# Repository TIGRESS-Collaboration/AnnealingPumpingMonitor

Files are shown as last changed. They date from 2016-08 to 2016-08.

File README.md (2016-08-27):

# AnnealingPumpingMonitor
Contains code and PCD designs and documentation regarding the remote monitor station for HPGe detector annealing and pumping.

In PAMonitor_Interface_Board you'll find the Eagle CAD design files for the PCB. 

In RaspberryPi_Code you'll find the home directory of the webserver which contains all the code necessary to run the monitor system.

Some notes:
1) The UUGear library included here must be used, there were some lines of code which needed to be commented out to tame excessive messages to the system logs.
2) readData.c is deprecated. Use readData.cpp
3) Same as above for build.sh and buildcpp.sh, respectively.
4) runMonitorStn.sh was to be a script that could be launched to do all work and checks necessary to ensure the monitor station would run, however, there are still some bugs to be ironed out.

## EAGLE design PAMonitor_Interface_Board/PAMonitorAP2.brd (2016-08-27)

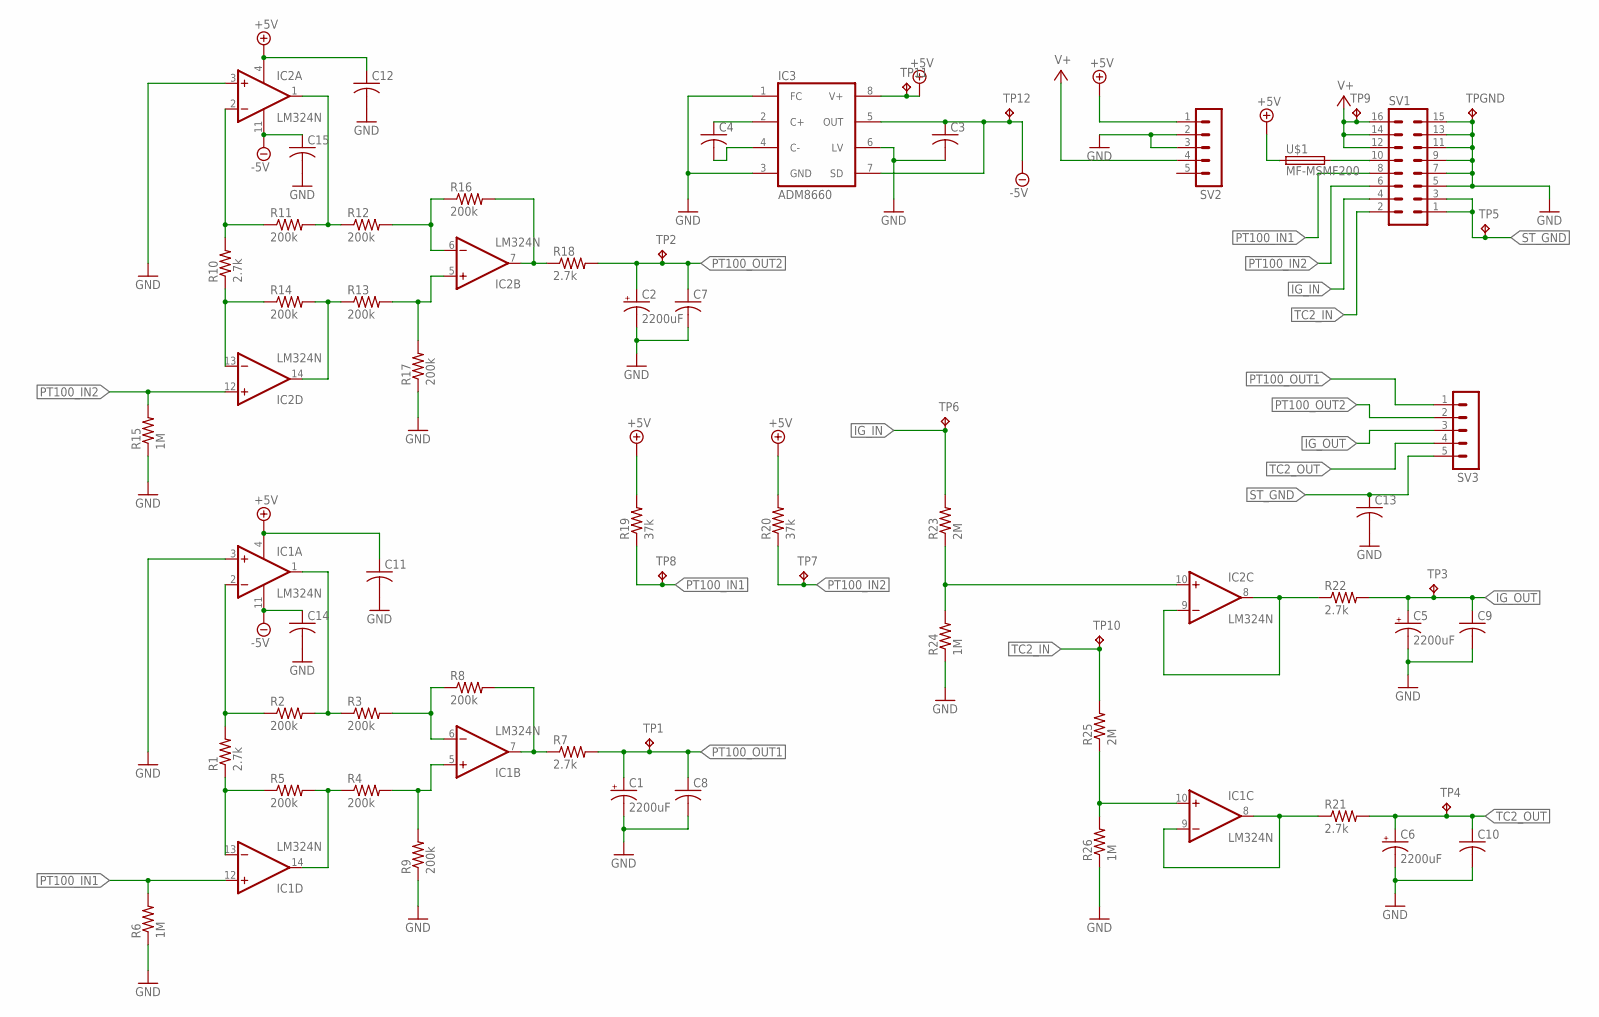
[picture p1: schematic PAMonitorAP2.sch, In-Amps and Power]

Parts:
C1, C2, C5, C6: 2200uF; E5-10,5
C3, C4, C7, C8, C9, C10, C11, C12, C13, C14, C15: C-US025-025X050; C025-025X050
IC1, IC2: LM324N; DIL14
IC3: ADM8660; ADM8660-DIL08
R1, R7, R10, R18, R21, R22: 2.7k; 0309/12
R2, R3, R4, R5, R8, R9, R11, R12, R13, R14, R16, R17: 200k; 0309/12
R6, R15, R24, R26: 1M; 0309/12
R19, R20: 37k; 0309/12
R23, R25: 2M; 0309/12
SV1: MA08-2
SV2, SV3: MA05-1
TP1, TP2, TP3, TP4, TP5, TP6, TP7, TP8, TP9, TP10, TP11, TP12: TPB2,54; B2,54
TPGND: TPB2,54; B2,54
U$1: MF-MSMF200

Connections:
+5V: C11.1, C12.1, IC1.4 (V+), IC2.4 (V+), IC3.8 (V+), R19.2, R20.2, SV2.1, TP11.TP, U$1.1
-5V: C3.1, C14.1, C15.1, IC1.11 (V-), IC2.11 (V-), IC3.5 (OUT), IC3.7 (SD), TP12.TP
GND: C1.-, C2.-, C3.2, C5.-, C6.-, C7.2, C8.2, C9.2, C10.2, C11.2, C12.2, C13.2, C14.2, C15.2, IC1.3 (+IN), IC2.3 (+IN), IC3.1 (FC), IC3.3 (GND), IC3.6 (LV), R6.1, R9.1, R15.1, R17.1, R24.1, R26.1, SV1.5, SV1.7, SV1.9, SV1.11, SV1.13, SV1.15, SV2.2, SV2.3, TPGND.TP
IG_IN: R23.2, SV1.4, TP6.TP
IG_OUT: C5.+, C9.1, R22.2, SV3.3, TP3.TP
unnamed: IC1.13 (-IN), R1.1, R5.1
unnamed: IC1.2 (-IN), R1.2, R2.1
unnamed: IC1.1 (OUT), R2.2, R3.1
unnamed: IC1.6 (-IN), R3.2, R8.1
unnamed: IC1.5 (+IN), R4.2, R9.2
unnamed: IC1.14 (OUT), R4.1, R5.2
unnamed: IC1.7 (OUT), R7.1, R8.2
unnamed: IC2.13 (-IN), R10.1, R14.1
unnamed: IC2.2 (-IN), R10.2, R11.1
unnamed: IC2.1 (OUT), R11.2, R12.1
unnamed: IC2.6 (-IN), R12.2, R16.1
unnamed: IC2.5 (+IN), R13.2, R17.2
unnamed: IC2.14 (OUT), R13.1, R14.2
unnamed: IC2.7 (OUT), R16.2, R18.1
unnamed: C4.1, IC3.2 (C+)
unnamed: C4.2, IC3.4 (C-)
unnamed: SV1.10, U$1.2
unnamed: IC2.8 (OUT), IC2.9 (-IN), R22.1
unnamed: IC1.8 (OUT), IC1.9 (-IN), R21.1
unnamed: IC1.10 (+IN), R25.1, R26.2
unnamed: IC2.10 (+IN), R23.1, R24.2
PT100_IN1: IC1.12 (+IN), R6.2, R19.1, SV1.8, TP8.TP
PT100_IN2: IC2.12 (+IN), R15.2, R20.1, SV1.6, TP7.TP
PT100_OUT1: C1.+, C8.1, R7.2, SV3.1, TP1.TP
PT100_OUT2: C2.+, C7.1, R18.2, SV3.2, TP2.TP
ST_GND: C13.1, SV1.1, SV1.3, SV3.5, TP5.TP
TC2_IN: R25.2, SV1.2, TP10.TP
TC2_OUT: C6.+, C10.1, R21.2, SV3.4, TP4.TP
V+: SV1.12, SV1.14, SV1.16, SV2.4, TP9.TP

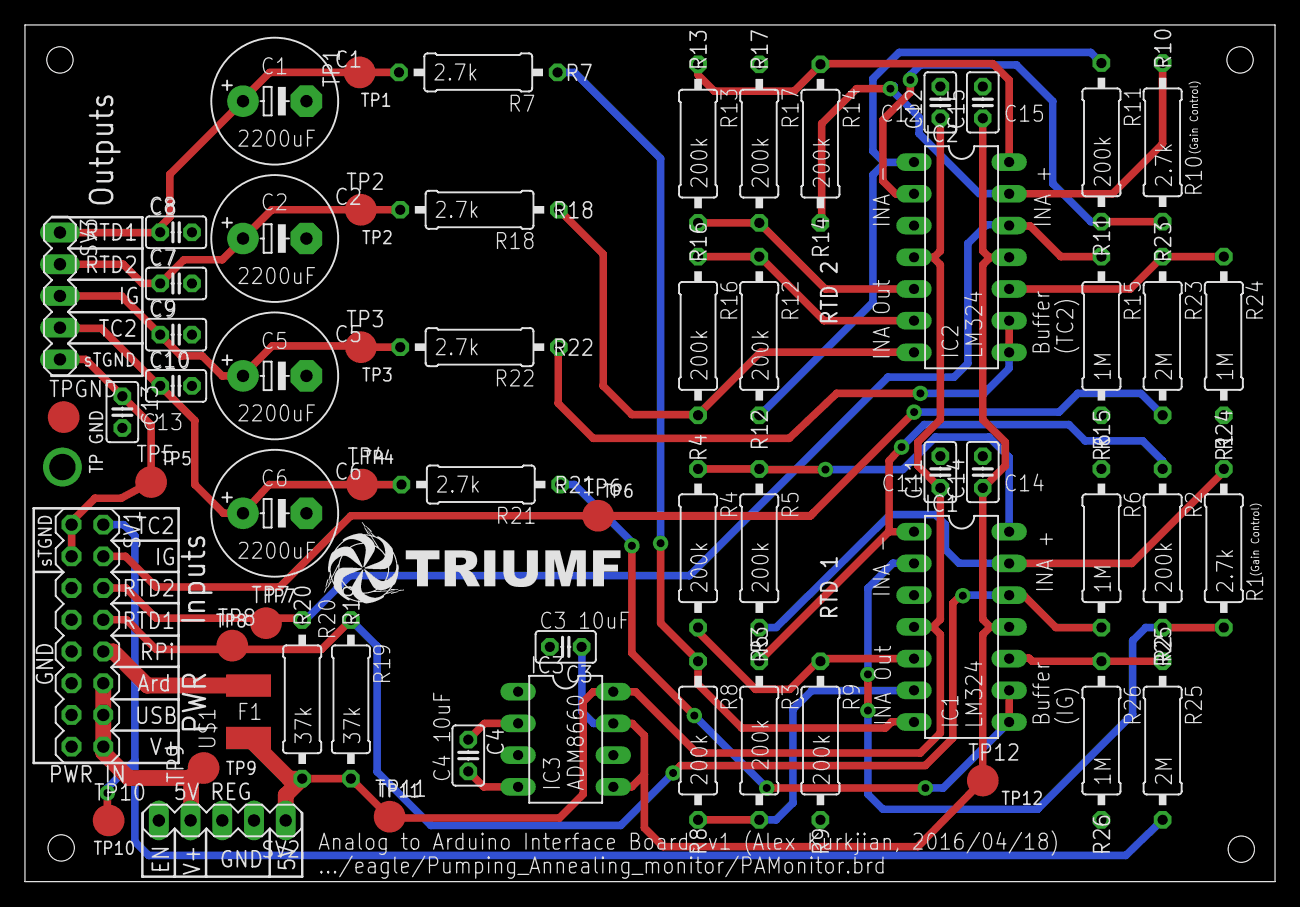
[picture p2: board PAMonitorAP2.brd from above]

Board: 2 copper layers, 100.1 x 68.6 mm, 61 parts (0 on the bottom side), 34 nets.

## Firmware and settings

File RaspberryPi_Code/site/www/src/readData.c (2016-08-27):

#include <stdlib.h>
#include <stdio.h>
#include <string.h>
#include <sys/stat.h>
#include <sys/types.h>
#include <mqueue.h>
#include <unistd.h>
#include <time.h>
#include <math.h>

#include "srcUUGear/UUGear.h"

//Define constants

#define EXTERNAL 1		// For external ADC reference voltage
#define INTERNAL 0		// For Vcc to be the ADC reference voltage
#define ADC_RES 1023	// ADC resolution
#define GAIN_IG 3.29
#define GAIN_TC2 3.33
#define SAMPLE_NUM 100
#define PAST_NUM 15
#define PIN_NUM 4


#define IG_ALGORITHM 11 // For the Ion-Gauge pressure conversion
#define TC_ALGORITHM 4  // For the thermocouple pressure conversion

#ifndef TEMP_CONV_1
	#define TEMP_CONV_1 146.8331143
#endif

#ifndef TEMP_OFFSET_1
	#define TEMP_OFFSET_1 -260.9097503
#endif

#ifndef TEMP_CONV_2
    #define TEMP_CONV_2 132.7957508
#endif

#ifndef TEMP_OFFSET_2
    #define TEMP_OFFSET_2 -234.2247224
#endif

#ifndef PT100_IN1 		// Define the input pins
	#define PT100_IN1 2
#endif 

#ifndef PT100_IN2
	#define PT100_IN2 3
#endif

#ifndef IG_IN
	#define IG_IN 5
#endif

#ifndef TC2_IN
	#define TC2_IN 4
#endif

#ifndef CAL_PT100 		// These are FINAL READING calibrations (ie. in Volts, degree Celsius, Torr, etc...)
	#define CAL_PT100 0.0
#endif

#ifndef CAL_IG
    #define CAL_IG -0.1 // This is likely to change later
#endif

#ifndef CAL_TC2
    #define CAL_TC2 -0.00 // This is likely to change later
#endif

#ifndef CAL_5V
	#define CAL_5V 3.325
#endif

// Just some conversion functions for temperature and pressure
// double cal is the calibration offset between the measurement from the detector lab boxes to the calculated value here
float volt2Pressure(double voltage, int expFactor, float gain, double cal) {
	int exp;
	float pressure;

	voltage = (voltage + cal)* gain;
	exp = (int)floor(voltage) - expFactor;

	// Decode the mantissa
	if (exp < 0) 
		pressure = ((voltage - floor(voltage) + 0.1) / 0.11)/pow(10,-1*exp);
	else
		pressure = ((voltage - floor(voltage) + 0.1) / 0.11)*pow(10,exp);
	 
	return pressure;
}

float volt2Temperature(float voltage, float conv, float offset, double cal) {
    double temp;

	temp = (double) ((voltage+cal) * conv + offset); // Simple linear relation

    return temp;
}

// Simple moving average filter 
float filterSMA(int newData[PIN_NUM], int oldData[PAST_NUM * PIN_NUM], float average[PIN_NUM]) {
	int ii, jj;
	int sum[PIN_NUM];

	// First shift all old values back in old array
	for (ii = 0; ii < PIN_NUM; ii++) {
		sum[ii] = 0;
		for (jj = ii * PAST_NUM; jj < PAST_NUM * (ii + 1); jj++) {
			if (jj == PAST_NUM * (ii + 1) - 1) {
				oldData[jj] = newData[ii];
			} else {
				oldData[jj] = oldData[jj + 1];
			}
			sum[ii] += oldData[jj]; // Then add the new value to the current sum.
		}			
		average[ii] = (float) sum[ii] / PAST_NUM; // Take the average
	}
}

// This is the overall noise filter. It has 3 steps:
// 1) Take a sample set of data. Order them
// 2) Take the mean of the median values in the ordered set
// 3) Thilter this value further by taking the simple moving average with previous measured values
float readADCNoiseFilter(UUGearDevice dev, int pin[PIN_NUM], float readings[PIN_NUM], int oldData[PIN_NUM * PAST_NUM]) {
	int sample[PIN_NUM * SAMPLE_NUM];
	int sum[PIN_NUM];
	float sumSMA[PIN_NUM];
	int swap = 0;
	int ii, jj;

	for (ii = 0; ii < PIN_NUM; ii++) {
		for (jj = ii * SAMPLE_NUM; jj < SAMPLE_NUM * (ii + 1); jj++) {
			sample[jj] = analogRead(&dev, pin[ii]);
			//usleep(500);
			//printf("Reading: %d from pin %d\n", sample[jj], pin[ii]);
		}
	}

    for (ii = 0; ii < PIN_NUM; ii++) {
        for (jj = ii * SAMPLE_NUM; jj < SAMPLE_NUM * (ii + 1); jj++) {
			if (sample[jj] > sample [jj + 1]) {
				swap = sample[jj];
				sample[jj] = sample[jj + 1];
	            sample[jj + 1] = swap;
			}
        }
    }

    for (ii = 0; ii < PIN_NUM; ii++) {
        sum[ii] = 0;
    }

    for (ii = 0; ii < PIN_NUM; ii++) {
        for (jj = 0; jj < 50; jj++) {
            sum[ii] += sample[ii*SAMPLE_NUM+25+jj];
        }
    }

	filterSMA(sum, oldData, sumSMA);

	for (ii = 0; ii < PIN_NUM; ii++) {
		readings[ii] = sumSMA[ii] / 50;
	}
}

int main(int argc, char **argv)
{
    setupUUGear();
    setShowLogs(1);
    UUGearDevice dev = attachUUGearDevice ("UUGear-Arduino-9046-1419");

	analogReference(&dev, EXTERNAL); // set AREF to external (3.3V regulated line, in this case)

    if (dev.fd != -1) {
		int j ; //, sumPT100Box, sumSTIG, sumSTTC2;
		//int senTorrIG = 5;		// analog in pin 5
		//int senTorrTC2 = 4;		// analog in pin 4
        //int pt100Box = 2;    	// analog input pin 2
		int oldADC[PIN_NUM * PAST_NUM];

		for (j = 0; j < PIN_NUM*PAST_NUM; j++) {
			oldADC[j] = 0;
		}

		char strCurrTime[21];
        float voltPT1001, voltPT1002 ;
		double voltSTIG, voltSTTC2;
		float tempPT1001, tempPT1002, presSTIG, presSTTC2;

		int pin[] = {PT100_IN1, PT100_IN2, IG_IN, TC2_IN};
		//int pinNum = sizeof(pin) / sizeof(int);

		float readings[PIN_NUM];

		voltPT1001 = 0; voltSTIG = 0; voltSTTC2 = 0;

		time_t pastTime;
		time(&pastTime);
		struct tm tmPTime;
		tmPTime  = *localtime(&pastTime);

		time_t currTime;
		struct tm tmCurrTime;

		// Initializing files
		FILE *currRead; // This should overwrite old file
		char currReadFN[] = "../../../mnt/EXFAT/datalogs/currentReading.txt";
	    printf("Creating file \"%s\"\n", currReadFN);
   	 	currRead = fopen(currReadFN, "w"); // Overwrite old file
    	if (currRead == NULL) {
        	perror("Failed to create and open file");
        	return EXIT_FAILURE;
    	}
    	fclose(currRead);


		FILE *datalog_timed; // This should simply create a new file
        char datalogTimedFN[56];
        strftime(datalogTimedFN, sizeof(datalogTimedFN), "../../../mnt/EXFAT/datalogs/datalog_%Y%m%d_%H%M%S.txt", &tmPTime);
        printf("Creating file \"%s\"\n", datalogTimedFN);
        datalog_timed = fopen(datalogTimedFN, "a"); // Append to old file (if it exists...)
        if (datalog_timed == NULL) {
            perror("Failed to create and open file");
            return EXIT_FAILURE;
        }
        fclose(datalog_timed);

		FILE *datalog; // This should simply create a new file
		char datalogFN[] = "../datalogs/datalog.txt";
		printf("Opening file \"%s\"\n", datalogFN);
		datalog = fopen(datalogFN, "a"); // Append to old file (if it exists...)
		if (datalog == NULL) {
            perror("Failed to create and open file");
            return EXIT_FAILURE;
        }
        fclose(datalog);
		
		

        while (1 == 1) {
/*
			sumPT100Box = 0;
			sumSTIG = 0;
			sumSTTC2 = 0;

			for (j = 0; j < 200; j++) {
				sumPT100Box += analogRead(&dev, pt100Box);
				sumSTIG += analogRead(&dev, senTorrIG);
				sumSTTC2 += analogRead(&dev, senTorrTC2);
			}

            voltPT100Box = (float)(sumPT100Box * 5 / 200) / 1023;
			voltSTIG = (float) (sumSTIG * 5 / 200) / 1023;
			voltSTTC2 = (float) (sumSTTC2 * 5 / 200) / 1023;
*/

			readADCNoiseFilter(dev, pin, readings, oldADC);

            voltPT1001 = (float)(readings[0] * CAL_5V) / ADC_RES;
			voltPT1002 = (float)(readings[1] * CAL_5V) / ADC_RES;

            voltSTIG = (float) (readings[2] * CAL_5V) / ADC_RES;
            voltSTTC2 = (float) (readings[3] * CAL_5V) / ADC_RES;

			presSTIG = volt2Pressure(voltSTIG, IG_ALGORITHM, GAIN_IG, CAL_IG);
			presSTTC2 = volt2Pressure(voltSTTC2, TC_ALGORITHM, GAIN_TC2, CAL_TC2);
			tempPT1001 = volt2Temperature(voltPT1001, TEMP_CONV_1, TEMP_OFFSET_1, CAL_PT100);
            tempPT1002 = volt2Temperature(voltPT1002, TEMP_CONV_2, TEMP_OFFSET_2, CAL_PT100);

			time(&currTime);
			tmCurrTime  = *localtime(&currTime);

			if(tmCurrTime.tm_mday > tmPTime.tm_mday) {
				strftime(datalogTimedFN, sizeof(datalogTimedFN), "../datalogs/datalog_%Y%m%d_%H%M%S.txt", &tmCurrTime);
        		printf("Creating file \"%s\"\n", datalogTimedFN);
        		datalog_timed = fopen(datalogTimedFN, "a"); // Append to old file (if it exists...)
        		if (datalog_timed == NULL) {
            		perror("Failed to create and open file");
            		return EXIT_FAILURE;
        		}
        		fclose(datalog_timed);
			}

			tmPTime = tmCurrTime;

			strftime(strCurrTime, sizeof(strCurrTime), "%F %H:%M:%S", &tmCurrTime);
			printf("Time: %s    PT100(1): %.1f C    PT100(2): %.1f C    IG: %.2E Torr    TC2: %.2E Torr\n", strCurrTime, tempPT1001, tempPT1002, presSTIG, presSTTC2);

			currRead = fopen(currReadFN, "w");
			fprintf(currRead, "<b>Time:</b> %s <br><b>PT100 (1):</b> %.1f\u2103 &nbsp; %.3fV <br><b>PT100 (2):</b> %.1f\u2103 &nbsp; %.3fV <br><b>IG:</b> %.2E Torr &nbsp; %.3fV<br><b>TC2:</b> %.2E Torr&nbsp; %.3fV", strCurrTime, tempPT1001, voltPT1001, tempPT1002, voltPT1002,  presSTIG, voltSTIG*GAIN_IG,  presSTTC2, voltSTTC2*GAIN_TC2);
			fflush(currRead);
			fsync(fileno(currRead));
			fclose(currRead);
			
			datalog = fopen(datalogFN, "a");
			fprintf(datalog, "%s\t %.1f\t %.3f\t %.1f\t %.3f\t %.2E\t %.3f\t %.2E\t %.3f\n", strCurrTime, tempPT1001, voltPT1001, tempPT1002, voltPT1002, presSTIG, voltSTIG, presSTTC2, voltSTTC2);
			fflush(datalog);
            fsync(fileno(datalog));
			fclose(datalog);

            datalog_timed = fopen(datalogTimedFN, "a");
			fprintf(datalog_timed, "%s\t %.1f\t %.3f\t %.1f\t %.3f\t %.2E\t %.3f\t %.2E\t %.3f\n", strCurrTime, tempPT1001, voltPT1001, tempPT1002, voltPT1002, presSTIG, voltSTIG, presSTTC2, voltSTTC2);
			fflush(datalog_timed);
            fsync(fileno(datalog_timed));
            fclose(datalog_timed);

            //usleep(5000000);
        }
        detachUUGearDevice(&dev);
    }
    else {
        printf("Can not open UUGear device.\n");
    }

    cleanupUUGear();

    return 0;
}

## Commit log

2016-08-27 PCB Design Files
    Uploaded board design files for the monitor station.
    [PAMonitorAP2.brd, PAMonitorAP2.sch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]
2016-08-27 Raspberry Pi Code Upload
    Raspberry Pi code used to run the monitor system. Note: Some
    modifications to the UUGear code were necessary to ensure the Raspberry
    Pi system logs wouldn't not become completely flooded and fill the
    filesystem with excess information.
    A few other things:
    - readData.C is deprecated, use readData.cpp
    - same goes for build.sh compared to buildcpp.sh
    - runMonitorStn.sh was to be a script that would compile and launch the
    everything automatically, but currently needs some issues ironed out
    [UUGearDaemon.c, readData.c]
